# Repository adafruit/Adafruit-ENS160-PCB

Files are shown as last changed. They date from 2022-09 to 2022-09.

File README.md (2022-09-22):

## Adafruit ENS160 MOX Gas Sensor PCB

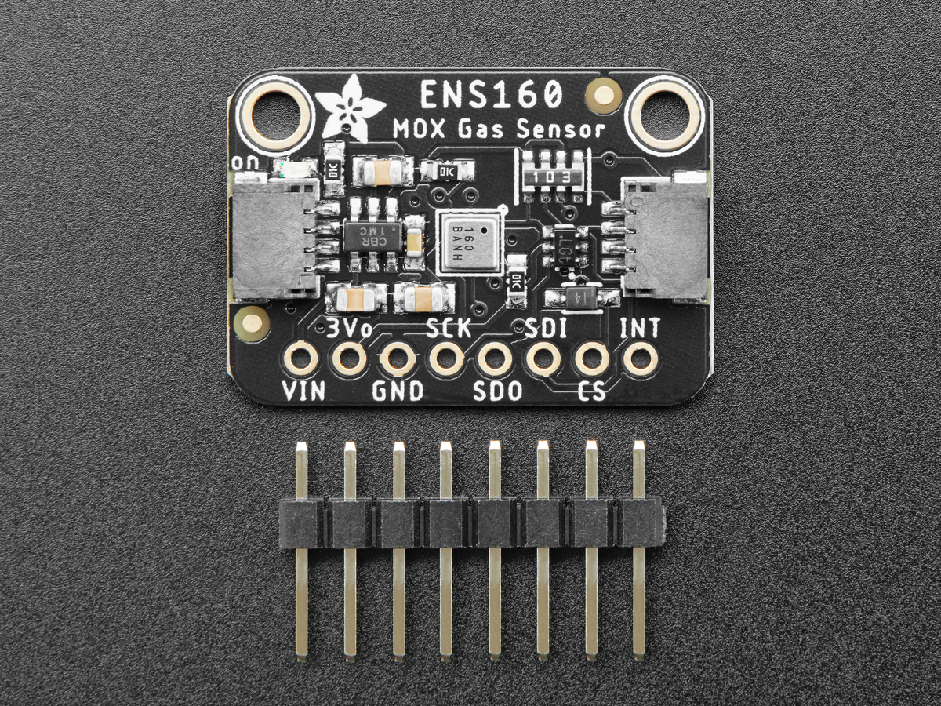
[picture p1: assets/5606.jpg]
<a href="http://www.adafruit.com/products/5606"><br/>
Click here to purchase one from the Adafruit shop</a>

PCB files for the Adafruit ENS160 MOX Gas Sensor. 

Format is EagleCAD schematic and board layout
* https://www.adafruit.com/product/5606

### Description

*sniff* *sniff* ... do you smell that? No need to stick your nose into a carton of milk anymore, you can build a digital nose with the ENS160 Gas Sensor, a fully integrated MOX gas sensor. This is a very fine air quality sensor from the sensor experts at ScioSense, with I2C interfacing so you don't have to manage the heater and analog reading of a MOX sensor. It combines multiple metal-oxide sensing and heating elements on one chip to provide more detailed air quality signals.

The ENS160 is the replacement for the popular, but now-discontinued CCS811. It has similar functionality but does require all new driver code so be aware if you are updating from an original design with the CCS811 that some work is required to upgrade.

The ENS160 has a 'standard' hot-plate MOX sensor, as well as a small microcontroller that controls power to the plate, reads the analog voltage, and provides an I2C interface to read from. ScioSense provides an Arduino library with examples of reading the four raw resistance values and also the TVOC and eCO2 and a Python/CircuitPython library that can be used with Linux computers like the Raspberry Pi or our CircuitPython boards.

Please note, this sensor, like all VOC/gas sensors, has variability, and to get precise measurements you will want to calibrate it against known sources! That said, for general environmental sensors, it will give you a good idea of trends and comparison.

Another nice element to this sensor is the ability to set temperature and humidity compensation for better accuracy. An external humidity sensor is required and then the RH% is written over I2C to the sensor, so it can better calibrate the MOX sensor reading and reduce humidity/temperature-based variations.

Nice sensor right? So we made it easy for you to get right into your next project. The surface-mount sensor is soldered onto a custom-made PCB in the STEMMA QT form factor, making them easy to interface with. The STEMMA QT connectors on either side are compatible with the SparkFun Qwiic I2C connectors. This allows you to make solderless connections between your development board and the ENS160 or to chain it with a wide range of other sensors and accessories using a compatible cable. QT Cable is not included, but we have a variety in the shop

We’ve of course broken out all the pins to standard headers and added a 3.3V voltage regulator and level shifting to allow you to use it with either 3.3V or 5V systems such as the Arduino Uno, or Feather M4.

### License

Adafruit invests time and resources providing this open source design, please support Adafruit and open-source hardware by purchasing products from [Adafruit](https://www.adafruit.com)!

Designed by Limor Fried/Ladyada for Adafruit Industries.

Creative Commons Attribution/Share-Alike, all text above must be included in any redistribution. 
See license.txt for additional details.

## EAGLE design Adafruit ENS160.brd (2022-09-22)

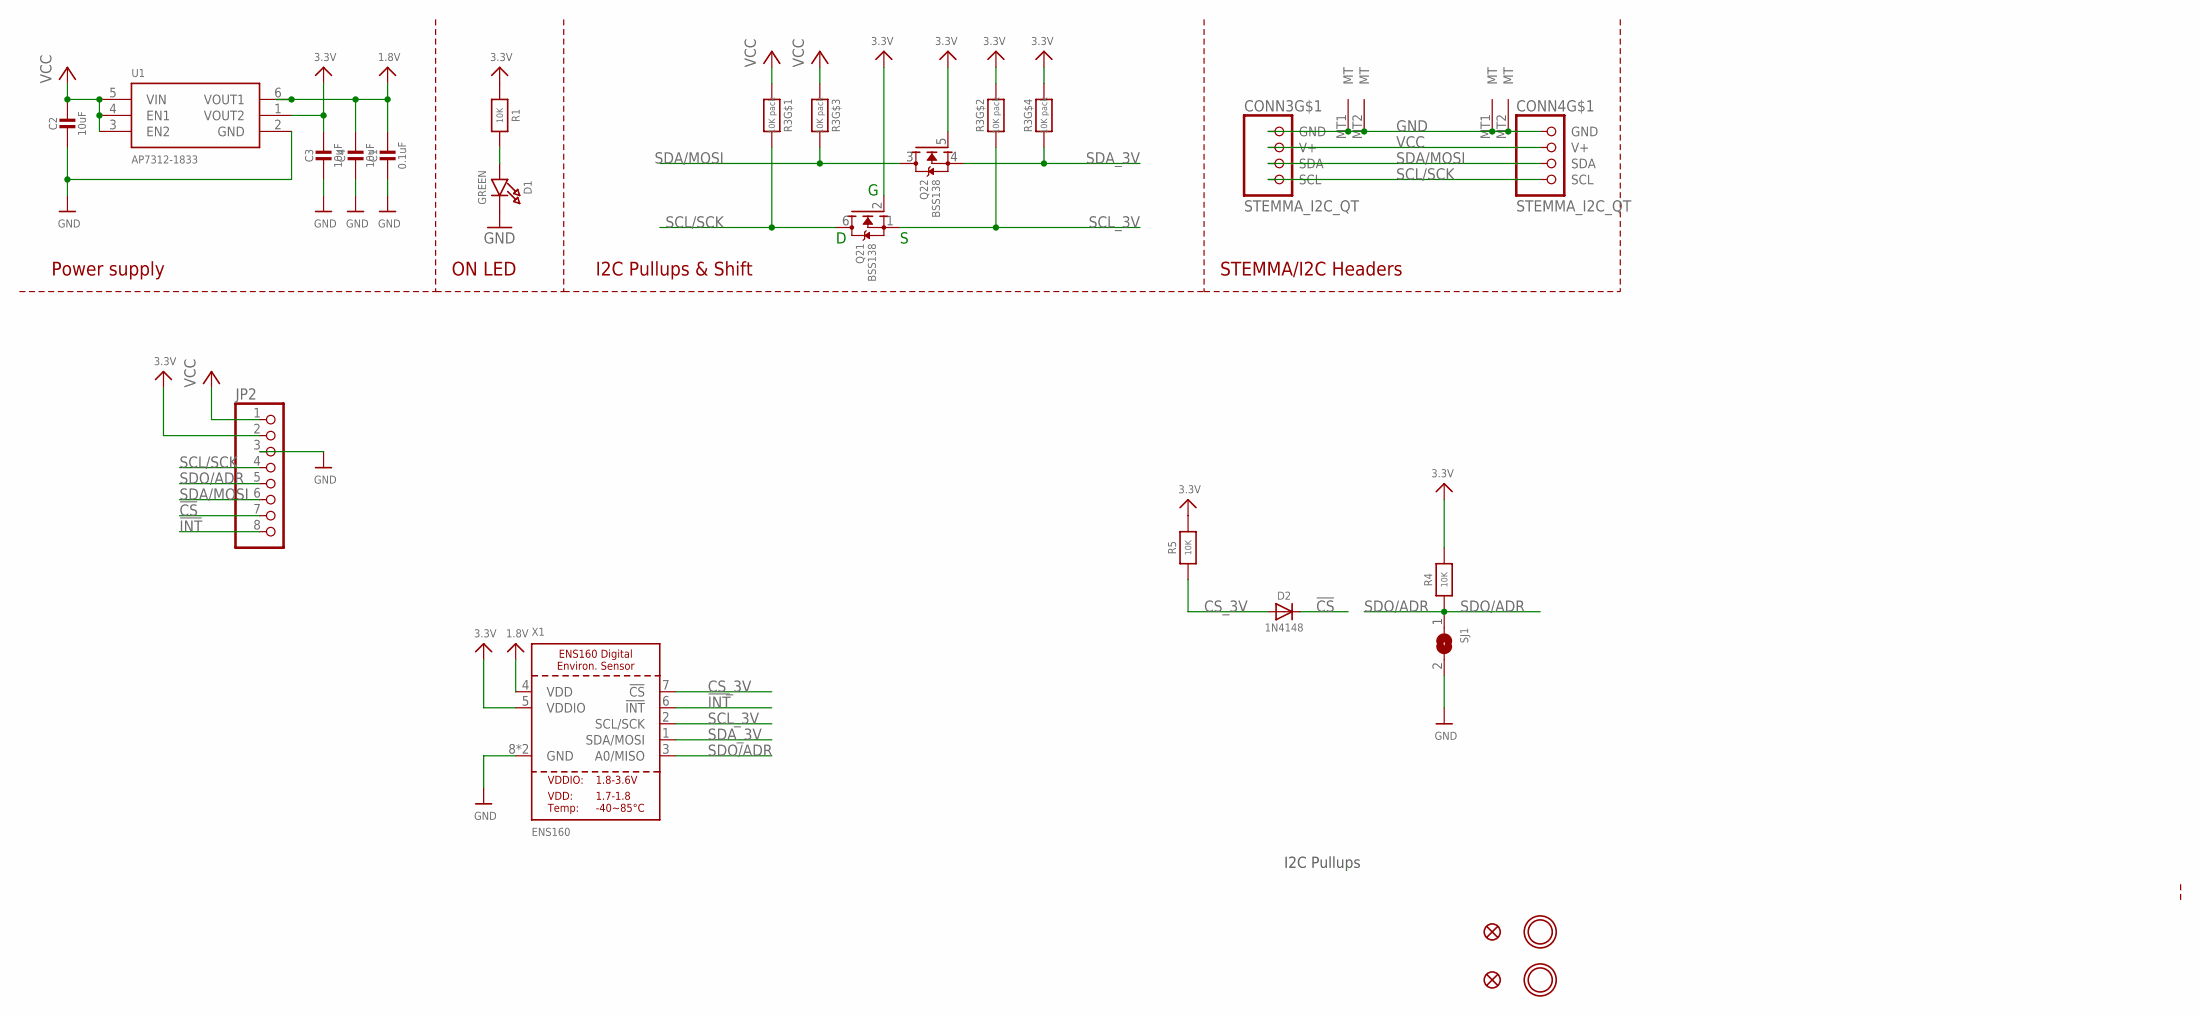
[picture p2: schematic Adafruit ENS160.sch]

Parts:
C1: 0.1uF; 0603-NO
C2, C3, C4: 10uF; 0805-NO
CONN3, CONN4: STEMMA_I2C_QT; JST_SH4
D1: GREEN; CHIPLED_0603_NOOUTLINE
D2: 1N4148; SOD-323
FID3, FID4: FIDUCIAL_1MM
JP2: HEADER-1X870MIL; 1X08_ROUND_70
Q2: BSS138; SOT363
R1, R4, R5: 10K; 0603-NO
R3: 10K pack; RESPACK_4X0603
SJ1: SOLDERJUMPER; SOLDERJUMPER_ARROW_NOPASTE
U1: AP7312-1833; SOT23-6
U$1, U$17: MOUNTINGHOLE2.5; MOUNTINGHOLE_2.5_PLATED
X1: ENS160

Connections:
1.8V: C1.1, C4.1, U1.6 (VOUT1), X1.4 (VDD)
3.3V: C3.1, JP2.2, Q2.2 (G), Q2.5 (G), R1.1, R3.2 (1), R3.4 (1), R4.2, R5.2, U1.1 (VOUT2), X1.5 (VDDIO)
!CS: D2.C, JP2.7
!INT: JP2.8, X1.6 (!INT)
CS_3V: D2.A, R5.1, X1.7 (!CS)
GND: C1.2, C2.2, C3.2, C4.2, CONN3.1 (GND), CONN3.MT1 (MT), CONN3.MT2 (MT), CONN4.1 (GND), CONN4.MT1 (MT), CONN4.MT2 (MT), D1.C, JP2.3, SJ1.2, U1.2 (GND), X1.8 (GND), X1.9 (GND)
unnamed: D1.A, R1.2
SCL/SCK: CONN3.4 (SCL), CONN4.4 (SCL), JP2.4, Q2.6 (D), R3.8 (2)
SCL_3V: Q2.1 (S), R3.7 (2), X1.2 (SCL/SCK)
SDA/MOSI: CONN3.3 (SDA), CONN4.3 (SDA), JP2.6, Q2.3 (D), R3.6 (2)
SDA_3V: Q2.4 (S), R3.5 (2), X1.1 (SDA/MOSI)
SDO/ADR: JP2.5, R4.1, SJ1.1, X1.3 (A0/MISO)
VCC: C2.1, CONN3.2 (V+), CONN4.2 (V+), JP2.1, R3.1, R3.3 (1), U1.3 (EN2), U1.4 (EN1), U1.5 (VIN)

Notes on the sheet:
I2C Pullups & Shift
STEMMA/I2C Headers
ON LED
Power supply
I2C Pullups

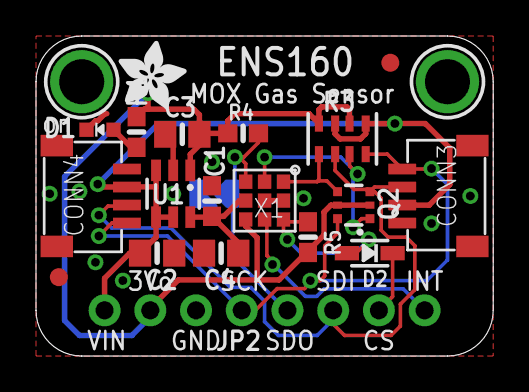
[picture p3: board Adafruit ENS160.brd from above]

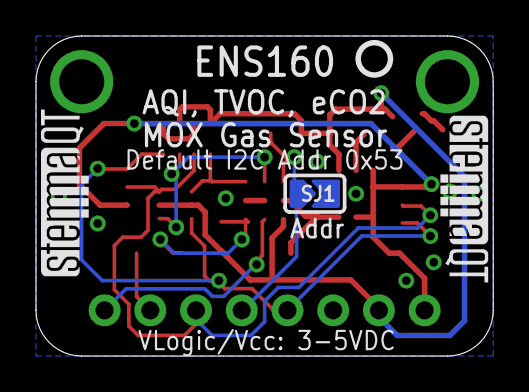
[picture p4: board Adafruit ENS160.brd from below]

Board: 2 copper layers, 25.4 x 17.8 mm, 25 parts (4 on the bottom side), 13 nets.

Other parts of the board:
U$20: ADAFRUIT_3.5MM
U$25: PCBFEAT-REV-040
U$30, U$31: STEMMAQT

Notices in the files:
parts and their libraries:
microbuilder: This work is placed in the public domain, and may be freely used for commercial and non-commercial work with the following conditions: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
